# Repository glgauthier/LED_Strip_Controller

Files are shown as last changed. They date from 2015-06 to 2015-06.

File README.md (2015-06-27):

#LED Strip Controller

A project for controlling cheap 5050 LED strips better than their factory 
made controllers. 

#Version 1 (Completed):
-Support for the features found in the factory controller as well as
audio response

-Uses button input rather than IR remote

-Based on ATMEGA328P with Arduino bootloader

#Version 2 (In the works):
-Same features as previous version as well as an added IR receiver so
that it can work with any remote

-Much cleaner code, schematic, and board design

-Based on ATTINY85; cheaper and just as useful!

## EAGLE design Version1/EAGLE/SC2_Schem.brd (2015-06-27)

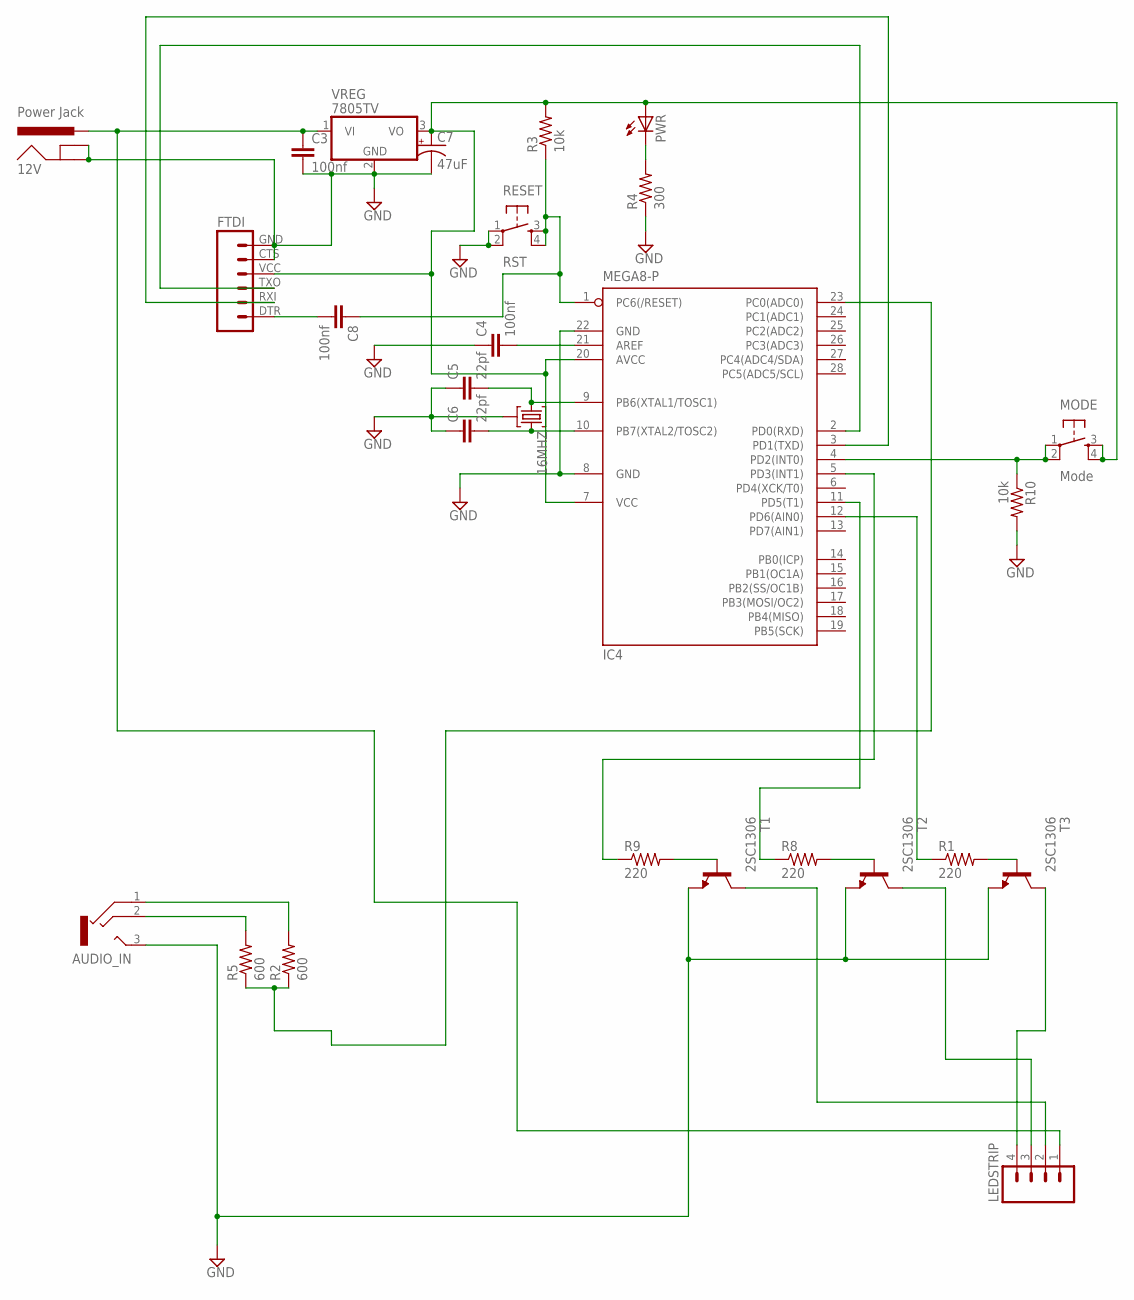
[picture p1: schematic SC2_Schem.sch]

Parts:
12V: Power Jack; POWER_JACK_PTH
16MHZ: 10G7A-12.5KHZ; HC49U
AUDIO_IN: 1503_04
C3, C4, C8: 100nf; CAP-PTH-5MM
C5, C6: 22pf; CAP-PTH-5MM
C7: 47uF; CPOL-RADIAL-100UF-25V
FTDI: FTDI_BASICPTH; FTDI_BASIC
IC4: MEGA8-P; DIL28-3
LEDSTRIP: M041X04_NO_SILK; 1X04_NO_SILK
MODE: Mode; TACTILE-PTH
PWR: LED5MM
R1, R8, R9: 220; AXIAL-0.3
R2, R5: 600; AXIAL-0.3
R3: 10k; AXIAL-0.3EZ
R4: 300; AXIAL-0.3EZ
R10: 10k; AXIAL-0.3
RESET: RST; TACTILE-PTH
T1, T2, T3: 2SC1306; TO220BV
VREG: 7805TV; TO220V

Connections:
GND: 12V.GND, 12V.GNDBREAK, 16MHZ.2, AUDIO_IN.3 (2), C3.2, C4.1, C5.1, C6.1, C7.2 (-), FTDI.CTS (5), FTDI.GND (6), IC4.8 (GND), IC4.22 (GND), R4.P$1 (1), R10.P$2 (2), RESET.1, RESET.2, T1.3 (E), T2.3 (E), T3.3 (E), VREG.2 (GND)
unnamed: R9.P$2 (2), T1.1 (B)
unnamed: IC4.23 (PC0(ADC0)), R2.P$1 (1), R5.P$1 (1)
unnamed: C4.2, IC4.21 (AREF)
unnamed: PWR.K (C), R4.P$2 (2)
unnamed: R8.P$2 (2), T2.1 (B)
unnamed: AUDIO_IN.1, R2.P$2 (2)
unnamed: R1.P$2 (2), T3.1 (B)
unnamed: IC4.5 (PD3(INT1)), R9.P$1 (1)
unnamed: IC4.11 (PD5(T1)), R8.P$1 (1)
unnamed: 16MHZ.1, C5.2, IC4.9 (PB6(XTAL1/TOSC1))
unnamed: 16MHZ.3, C6.2, IC4.10 (PB7(XTAL2/TOSC2))
unnamed: AUDIO_IN.2 (3), R5.P$2 (2)
unnamed: C8.1, IC4.1 (PC6(/RESET)), R3.P$1 (1), RESET.3, RESET.4
unnamed: FTDI.TXO (3), IC4.2 (PD0(RXD))
unnamed: FTDI.RXI (2), IC4.3 (PD1(TXD))
unnamed: C8.2, FTDI.DTR (1)
unnamed: IC4.12 (PD6(AIN0)), R1.P$1 (1)
unnamed: IC4.4 (PD2(INT0)), MODE.1, MODE.2, R10.P$1 (1)
unnamed: LEDSTRIP.2, T1.2 (C)
unnamed: LEDSTRIP.3, T2.2 (C)
unnamed: LEDSTRIP.4, T3.2 (C)
unnamed: C7.1 (+), FTDI.VCC (4), IC4.7 (VCC), IC4.20 (AVCC), MODE.3, MODE.4, PWR.A, R3.P$2 (2), VREG.3 (VO)
V+: 12V.PWR, C3.1, LEDSTRIP.1, VREG.1 (VI)

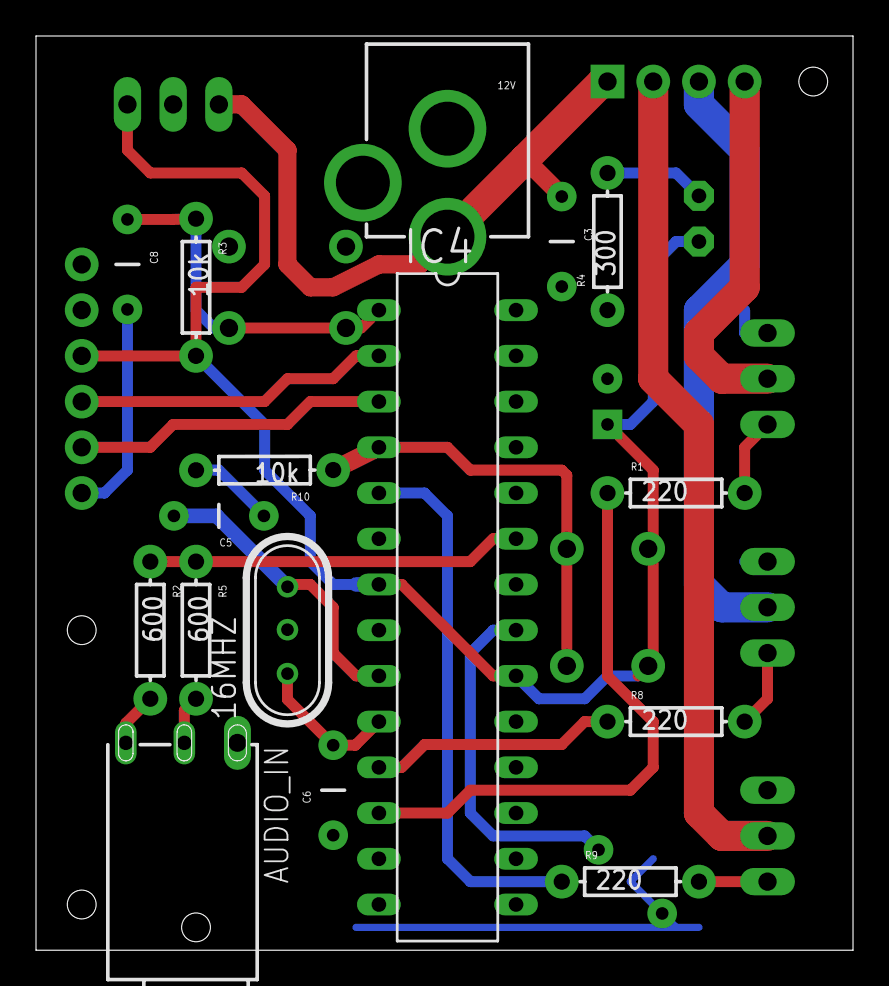
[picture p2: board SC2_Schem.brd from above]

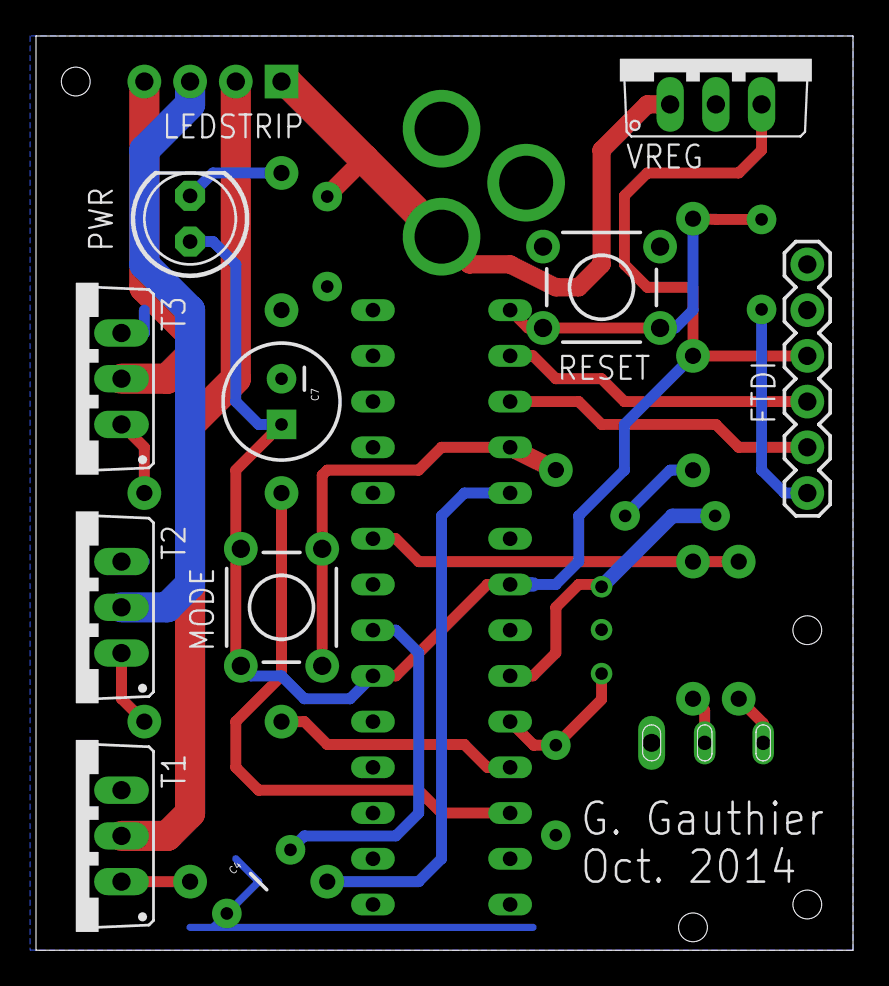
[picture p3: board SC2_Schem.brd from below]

Board: 2 copper layers, 45.4 x 50.8 mm, 27 parts (11 on the bottom side), 24 nets.

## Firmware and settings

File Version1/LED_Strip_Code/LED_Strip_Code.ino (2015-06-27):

#define REDPIN 5
#define GREENPIN 3
#define BLUEPIN 6
int b = 0;
int r = 0;
int g = 0;
int FADESPEED = 25;
int STROBESPEED = 50;

int music = 0;
int mode = 0;

//~~~~~~~~~~~~~~~~~~~~~~~~~~~~Setup Loop~~~~~~~~~~~~~~~~~~~~~~~~~~~~~~~~~~~~~~~~~~~~~~~~~~~
void setup() {
  pinMode(REDPIN, OUTPUT);
  pinMode(GREENPIN, OUTPUT);
  pinMode(BLUEPIN, OUTPUT);
  pinMode(A0, INPUT);
  pinMode(2, INPUT);
  attachInterrupt(0, changemode, CHANGE); //interrupt for mode change on pin 2 (I.0)
  
  analogWrite(REDPIN, 60);
  analogWrite(GREENPIN, 60);
  analogWrite(BLUEPIN, 60);
  delay(333);  
  analogWrite(REDPIN, 150);
  analogWrite(GREENPIN, 150);
  analogWrite(BLUEPIN, 150);
  delay(333); 
  
}

//~~~~~~~~~~~~~~~~~~~~~~~~~~~~Interrupt Loop~~~~~~~~~~~~~~~~~~~~~~~~~~~~~~~~~~~~~~~~~~~~~~~
void changemode(){

 static unsigned long last_interrupt_time = 0; //used to debounce button press
 unsigned long interrupt_time = millis(); //used to debounce button press
 if (interrupt_time - last_interrupt_time > 200){ //if the button has been pressed..
   if (mode < 12) mode++;
   else mode = 0;
 }
 last_interrupt_time = interrupt_time;
}

//~~~~~~~~~~~~~~~~~~~~~~~~~~~~ Main Loop ~~~~~~~~~~~~~~~~~~~~~~~~~~~~~~~~~~~~~~~~~~~~~~~~~~
void loop() { //normal loop

//-----------Mode 0 - White Light -------------------------------//  
  while (mode == 0) {
    if (digitalRead(2) == HIGH) break;
    analogWrite(BLUEPIN, 200);
    analogWrite(REDPIN, 200);
    analogWrite(GREENPIN, 200);
  }

//-----------Mode 1 - Music Reactance----------------------------//  
 while (mode == 1){
  if (digitalRead(2) == HIGH) break;
    analogWrite(BLUEPIN, b);
    analogWrite(REDPIN, r);
    analogWrite(GREENPIN, g);
  
    music = analogRead(0);
    
    if (music>50 & music<200) b = (b + 25);
      else b=100; 
  
    if (music>350 ) g = (255);
      else(g= 0) ;
      
    if (music>150){ 
      r=(r+70);
      b=(b+95);
    }
    else { 
      if (r>0 & b>0){ 
        r=(r-10); 
        b=(b-15);
      }
      else {
      r=0; 
      b=0;
      }
    }
  }

//--------------Mode 2- Music (more reactive)------------------------------------//  
 while (mode == 2){
  if (digitalRead(2) == HIGH) break;
    analogWrite(BLUEPIN, b);
    analogWrite(REDPIN, r);
    analogWrite(GREENPIN, g);
  
    music = analogRead(0);
    
    if (music>15 & music<50) b = (b + 50);
      else b=100; 
  
    if (music>150 ) g = (255);
      else(g= 0) ;
      
    if (music>50){ 
      r=(r+100);
      b=(b+120);
    }
    else { 
      if (r>0 & b>0){ 
        r=(r-10); 
        b=(b-25);
      }
      else {
      r=0; 
      b=0;
      }
    }
  }
 
//-------------------Mode 3 - Red-------------------------------//  
 while (mode == 3){
   if (digitalRead(2) == HIGH) break;
    analogWrite(BLUEPIN, 0);
    analogWrite(REDPIN, 255);
    analogWrite(GREENPIN, 0);
  }

//-------------------Mode 4 - Orange----------------------------//  
  while (mode == 4){
    if (digitalRead(2) == HIGH) break;
    analogWrite(BLUEPIN, 0);
    analogWrite(REDPIN, 255);
    analogWrite(GREENPIN, 128);
  }

//-------------------Mode 5- Yellow-----------------------------//  
   while (mode == 5){
    analogWrite(BLUEPIN, 0);
    analogWrite(REDPIN, 255);
    analogWrite(GREENPIN, 255);
  }

//-------------------Mode 6- Green------------------------------//  
   while (mode == 6){
    if (digitalRead(2) == HIGH) break;
    analogWrite(BLUEPIN, 0);
    analogWrite(REDPIN, 0);
    analogWrite(GREENPIN, 255);
  }

//--------------------Mode 7- Cyan------------------------------//  
   while (mode == 7){
    if (digitalRead(2) == HIGH) break;
    analogWrite(BLUEPIN, 255);
    analogWrite(REDPIN, 0);
    analogWrite(GREENPIN, 255);
  }

//--------------------Mode 8- Blue------------------------------//  
   while (mode == 8){
    if (digitalRead(2) == HIGH) break;
    analogWrite(BLUEPIN, 255);
    analogWrite(REDPIN, 0);
    analogWrite(GREENPIN, 0);
  }

//--------------------Mode 9- Purple-----------------------------//  
   while (mode == 9){
    if (digitalRead(2) == HIGH) break;
    analogWrite(BLUEPIN, 255);
    analogWrite(REDPIN, 128);
    analogWrite(GREENPIN, 0);
  }
  
//--------------------Mode 10- Violet-----------------------------//  
   while (mode == 10){
    if (digitalRead(2) == HIGH) break;
    analogWrite(BLUEPIN, 255);
    analogWrite(REDPIN, 255);
    analogWrite(GREENPIN, 0);
  }

//-------------------Mode 11- Fader-----------------------//  
   while (mode == 11){
    if (digitalRead(2) == HIGH) break;
    int r2, g2, b2;
   
   for (r2 = 0; r2 < 255; r2++) { // fade from blue to violet
      if (digitalRead(2) == HIGH) break;
     analogWrite(REDPIN, r2);
     delay(FADESPEED);
   } 
   for (b2 = 255; b2 > 0; b2--) { // fade from violet to red
      if (digitalRead(2) == HIGH) break;
     analogWrite(BLUEPIN, b2);
     delay(FADESPEED);
   } 
   for (g2 = 0; g2 < 255; g2++) { // fade from red to yellow
       if (digitalRead(2) == HIGH) break;
      analogWrite(GREENPIN, g2);
      delay(FADESPEED);
  } 
  for (r2 = 255; r2 > 0; r2--) { // fade from yellow to green
     if (digitalRead(2) == HIGH) break;
    analogWrite(REDPIN, r2);
    delay(FADESPEED);
  } 
  for (b2 = 0; b2 < 255; b2++) { // fade from green to teal
     if (digitalRead(2) == HIGH) break;
    analogWrite(BLUEPIN, b2);
    delay(FADESPEED);
  } 
  for (g2 = 255; g2 > 0; g2--) { // fade from teal to blue
     if (digitalRead(2) == HIGH) break;
    analogWrite(GREENPIN, g2);
    delay(FADESPEED);
  } 
  }
//-------------------Mode 12- Flasher-----------------------//  
  while (mode == 12){
    if (digitalRead(2) == HIGH) break;
    analogWrite(REDPIN, 255);
    analogWrite(GREENPIN, 0);
    analogWrite(BLUEPIN, 0);
    delay(333);  
    analogWrite(REDPIN, 255);
    analogWrite(GREENPIN, 0);
    analogWrite(BLUEPIN, 255);
    if (digitalRead(2) == HIGH) break;
    delay(333);  
    analogWrite(REDPIN, 0);
    analogWrite(GREENPIN, 0);
    analogWrite(BLUEPIN, 255);
    if (digitalRead(2) == HIGH) break;
    delay(333);  
    analogWrite(REDPIN, 0);
    analogWrite(GREENPIN, 255);
    analogWrite(BLUEPIN, 255);
    if (digitalRead(2) == HIGH) break;
    delay(333);  
    analogWrite(REDPIN, 0);
    analogWrite(GREENPIN, 255);
    analogWrite(BLUEPIN, 0);
    if (digitalRead(2) == HIGH) break;
    delay(333);  
    analogWrite(REDPIN, 255);
    analogWrite(GREENPIN, 255);
    analogWrite(BLUEPIN, 0);
    if (digitalRead(2) == HIGH) break;
    delay(333);  
  }
}

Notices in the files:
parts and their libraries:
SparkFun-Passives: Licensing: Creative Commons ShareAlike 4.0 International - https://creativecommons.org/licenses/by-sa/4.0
